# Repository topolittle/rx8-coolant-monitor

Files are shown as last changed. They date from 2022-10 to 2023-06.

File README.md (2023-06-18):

# MAZDA RX-8 Coolant monitor

The Mazda RX-8 lacks a proper gauge for displaying the coolant temperature. The stock gauge is more like a warning light than a real gauge. This project is about adding a display to the upper center console to display the coolant temperature and pressure. It also displays the battery voltage as a bonus.

This project doesn't use the OBD-II port, instead it uses dedicated sensors. The temperature sensor is from Delphi, which is very common in GM cars, and the pressure sensor is from AEM.

Although the project is for the Mazda RX-8, the electronic and the code could be used "as-is" for another car. The mechanical design, specifically the head unit, is made specific to integrate into aftermarket gauge pod, but it also should a stock RX-8 dashboard.

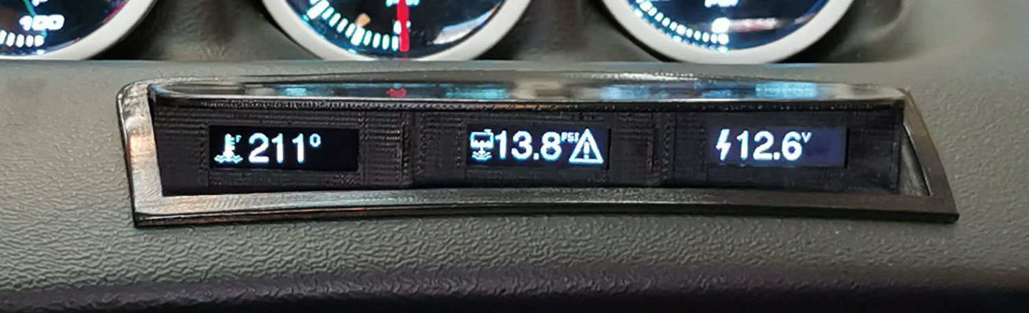
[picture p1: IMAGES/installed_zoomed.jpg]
Picture of the head unit installed in the car


# License
Except for the files listed below, this project is under the 3-clause BSD license.
## Exceptions
 - OLED_0.91_128x32.SLDASM: [This 3D drawing is from Grabcad](https://grabcad.com/library/oled-0-91-128x32-1) therefore its licenses only allows non-commercial use.
 - FreeSans18pt7bNum.h: This file contains source code from the [Adafruit-GFX-Library](https://github.com/adafruit/Adafruit-GFX-Library/) project, which is under the 2-clause BSD license. A copy of the license is provided beside the file.

# Trademarks
The RX-8 logo used in the source code provided here is a trademark of MAZDA MOTOR CORPORATION.

I am not associated with or sponsored by any of the companies mentioned in this project. I simply use their products for my personal and non-commercial use.

# Mechanical design
The mechanical design consists of two part:
- The enclosure for the PCB controller
- The head unit
## Head unit
The head unit contains three 128x32 OLED displays and it's designed to fit into a Lotek gauge pod, part #LTK-RX8-3DSH. The pod must be cut to accommodate the head unit. A cutting jig is included in the design, see below. Since the Lotek pod reproduces the same curved surface as the OEM dashboard, the design should fit a stock RX-8 without any modification.
### How to print:
Material: ASA (Do not use PLA since it will deform when exposed to the sun)
Layer height: 0.1mm
Supports: Yes, soluble for the best results
Difficulty: Expert
## Display holder
This is for holding the OLED displays in place. They require also an M3 screw each (See the BOM).
### How to print:
Material: ASA
Layer height: 0.2
Supports: No
Difficulty: Beginner
## Cutting JIG
Place the cutting JIG on the Lotek gauge pod, or on the stock dashboard pod, and mark the inside with a pen. This is where you have to cut. I used a Dremel with a small 0.5" saw blade attached to cut the pod.
### How to print:
Material: ASA, ABS or PLA
Layer height: 0.2
Supports: No
Difficulty: Beginner
## PCB Enclosure
It's a two parts enclosure: Top and bottom. The PCB goes inside and is held by four M4 screws (see the BOM). The bottom comes in two variants: One without anchor and one with two anchors for T-RAP. This can be useful if you don't want to use double sided tape to fix the enclosure inside the dashboard  

Note: Since the communication between the PCB controller and the head unit uses I2C, the controller should be placed as close to the head unit as possible. Avoid having more than 12 inches of cables between the two.
### How to print:
Material: ASA
Layer height: 0.2
Supports: No
Difficulty: Beginner
# Embedded
This is the code for the Arduino based Pro Micro. The main purpose is to read the actual values for various sensors and display the value on three independent OLED displays over I2C.
## Compile
You can use the Arduino IDE or you can use the provided devcontainer for VSCode. To do so:
1. Open the folder `EMBEDDED` with VSCode
2. View -> Command Palette
3. Type `Dev Containers: Reopen in Container`
4. Inside the container, use `ctrl_alt+R` to compile and `ctrl+alt+U` to upload  
 
Note: The devcontainer has been tested on Linux Fedora 35/36 and Oracle Linux 8.6. It might work with Windows 10+ under WSL2 but it's not tested.

## I2C multiplexing
Since the displays used here don't provide a way to configure their I2C address, the code multiplexes the data lines using extra I/O pins with the help of some *glue logic* components on the PCB.
## Temperature sensor (thermistor)
For reading the coolant temperature with a greater accuracy, an additional reference resistor is engaged at a specific temperature by a digital IO and a MOSFET on the PCB to lower the overall thermistor reference. This puts the reference resistor closer to the actual thermistor value at high temperature. A small hysteresis is in place to avoid switching back and forth the resistor too often. The conversion between the thermistor value and the actual temperature is achieved using the Steinhart-Hart equation. 
Note the project uses a Delphi temperature sensor but an AEM sensor can be used instead, see the BOM. If you want to use a different sensor than those two, you may have to adjust the three coefficients of the Steinhart-Hart equation inside the `getCoolantTempCelsius()` function.
## Reference voltage
Reading the battery voltage and the pressure sensor requires a precise reference voltage. To achieve better accuracy than using the internal Atmega 32U4 reference, an external reference voltage is used. The code reads the reference and makes appropriate corrections based on the actual read value.
## Unit of measure
You can choose between Celsius and Fahrenheit by pulling the digital I/O pin 8 high or low. The is a jumper on the PCB for that purpose.
## Customization
The file `coolant_monitor.h` contains definitions that can be customized to suit your needs. Here is the list of what you can customize:
- Coolant temperature high warning
- Coolant PSI high warning
- Battery voltage low warning
- Battery voltage high warning
- Display refresh rate
- Thermistor reference resistors
- Thermistor second reference resistor threshold and hysteresis
- Voltage divider values for the battery voltage
- Various analog to digital conversion parameters
- Various icons and logos
# Electronic
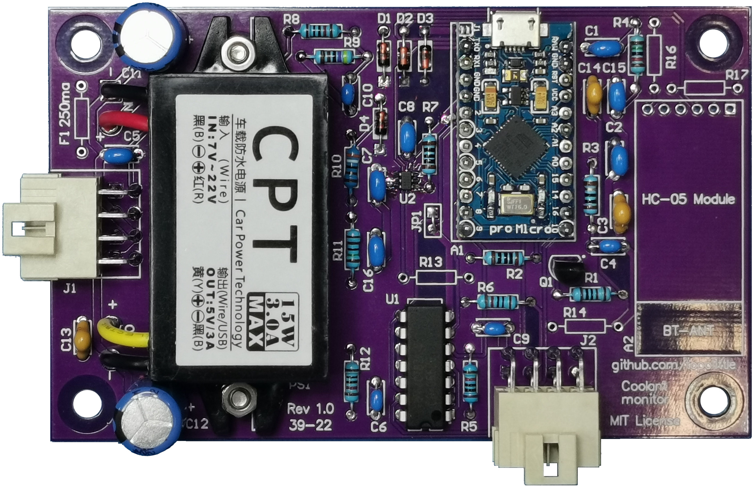
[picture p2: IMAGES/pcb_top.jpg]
Picture of the PCB, top view

A custom PCB incorporates the Adruino based Pro Micro and other important components. The main parts of this electronic design are:
- A DC-DC Converter to adapt the unstable voltage of the car (11V to 15V) to a steady 5V for the Pro Micro, sensors and other components
- A reference voltage for the various analog acquisitions performed by the Pro Micro
- The *glue logic* required to multiplex the I2C data lines
- Parking lights detection and protection circuit
- Voltage divider for reading the battery voltage
- Reference voltage for the coolant temperature thermistor
- Various signal filtration
- Connector for easily installing and removing the PCB and the enclosure from the car
- Optional Bluetooth module (not tested)
## Conformal coating
Since the PCB goes into a car, applying a silicon based conformal coating is required. Be sure to mask the connectors when doing so.
## Bluetooth
An optional Bluetooth HC-05 module can be added to control the unit. However, it doesn't have been tested as of version 1.0.  
Note: Using Bluetooth will require a custom Android app. Sorry for IOS users, it's standard Bluetooth, not Bluetooth MFI.  
Here are some future improvements which would be possible with Bluetooth:
- Over-The-Air firmware update, it may be possible with the stock bootloader, maybe not.
- Toggle the temperature units between Celsius and Fahrenheit
- Toggle the pressure units between PSI and Bar
- Display the coolant boiling point. Calculated base of a coolant/water ratio, configurable via Bluetooth
- Adjust the warning threshold for the various parameters
- Support for other sensers, configurable via Bluetooth

# Final product installed in the car
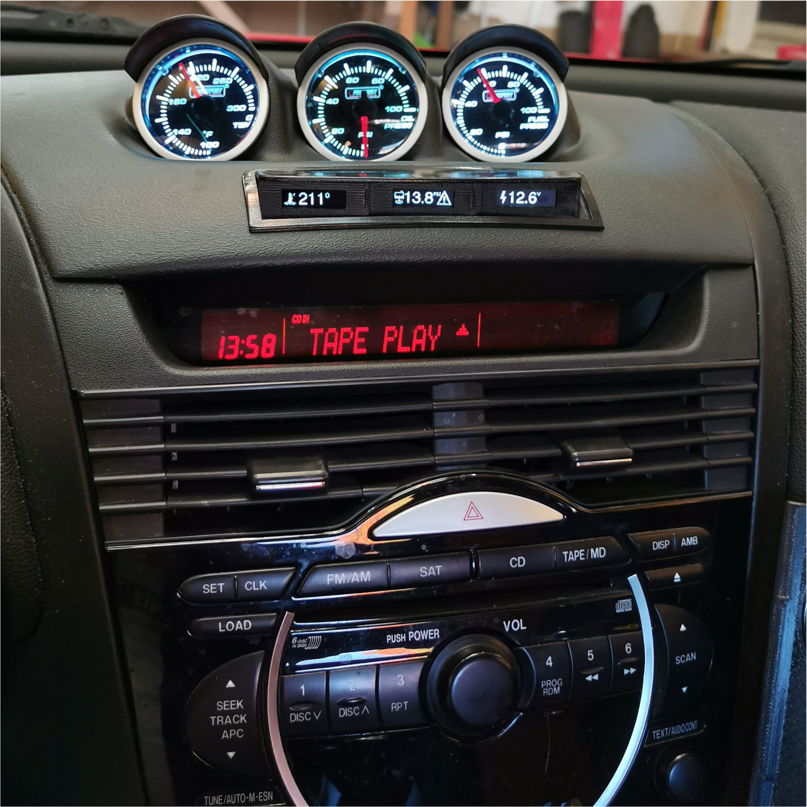
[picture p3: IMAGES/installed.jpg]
Picture of the unit installed in the car


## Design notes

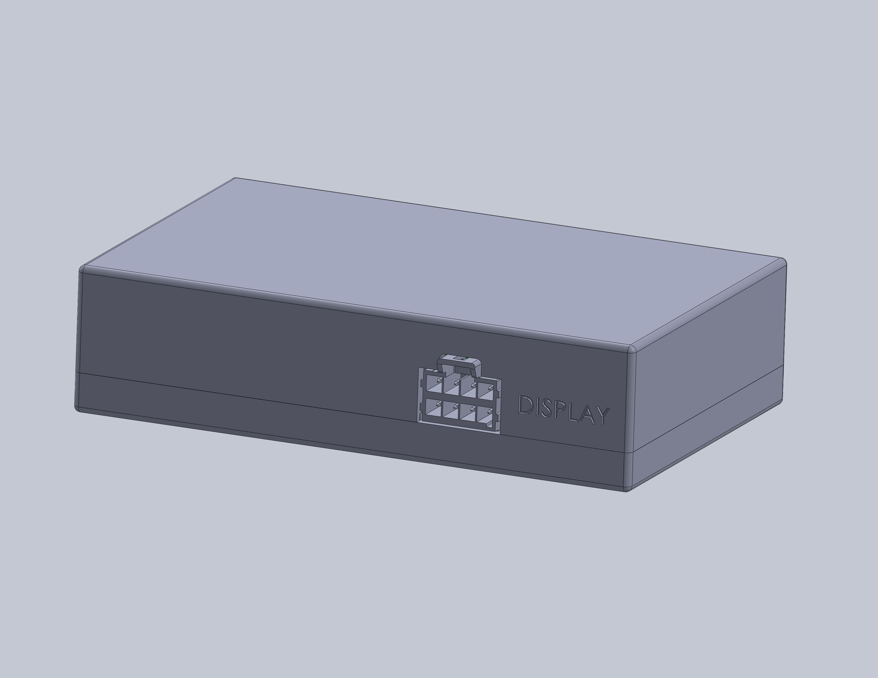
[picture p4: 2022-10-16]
MECHA/Controller_Enclosure/IMAGES/Enclosure_complete.PNG

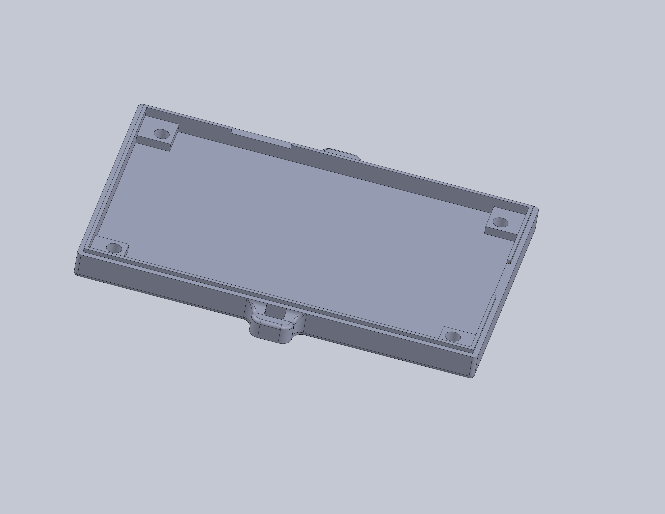
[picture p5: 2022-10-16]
MECHA/Controller_Enclosure/IMAGES/Enclosure_bottom_with_anchors.PNG

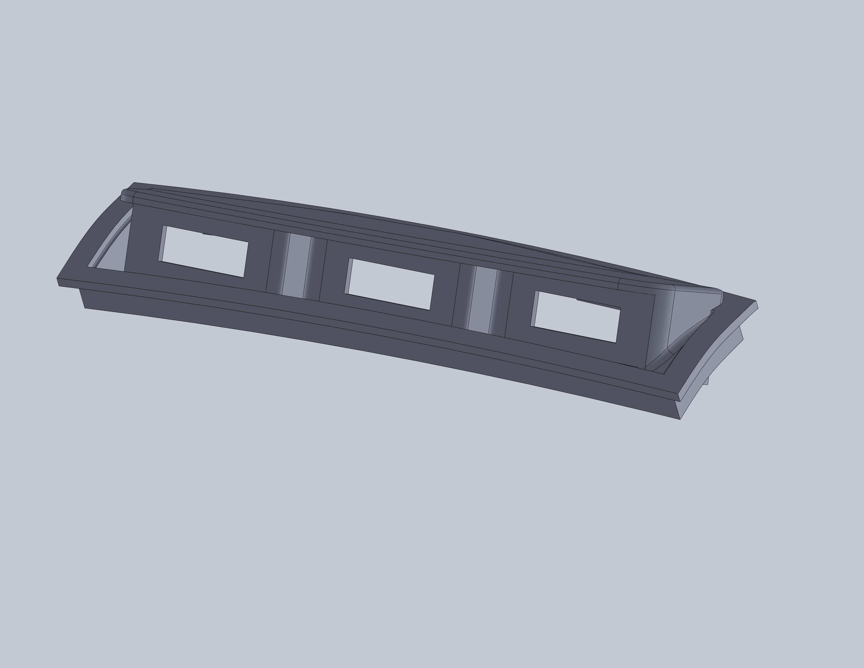
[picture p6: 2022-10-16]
MECHA/Head_Unit/IMAGES/Head_Unit.PNG

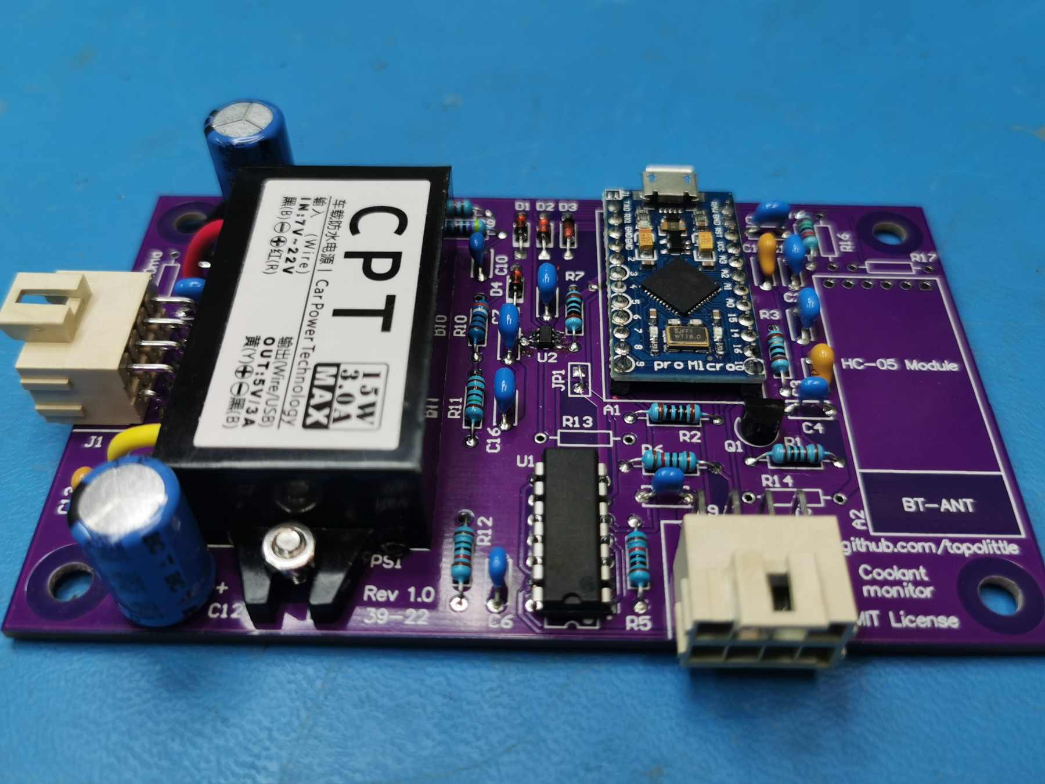
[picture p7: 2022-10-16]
IMAGES/pcb.jpg

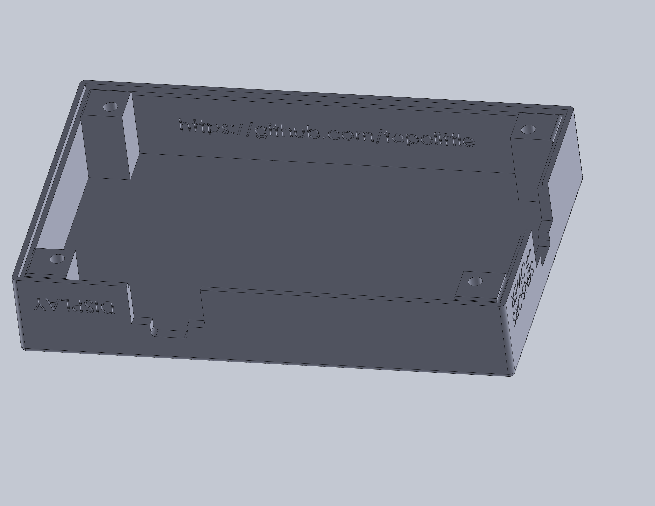
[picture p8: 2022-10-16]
MECHA/Controller_Enclosure/IMAGES/Enclosure_top.PNG

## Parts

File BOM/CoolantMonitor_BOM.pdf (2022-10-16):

Bill Of Material for RX-8 Coolant Monitor version 1.0

Main Board

Quantity Designator | Description | Value | Part # | Manufacturer | Digikey | Notes
1 A1 | Arduino MCU | Pro Micro 32U4 5V/16MHZ | DEV-12640 | Sparkfun
1 A2 | Bluetooth module | HC-05 | HC-05 | Many
7 C1, C2, C5, C7, C8, C15, C16 | Capacitor | 1uF | FG28X7R1E105KRT06 TDK | 445-173583-1-ND
3 C3, C13, C14 | Capacitor | 1nF | C315C102J3H5TA9170 Kemet | 399-17274-ND
4 C4, C6, C9, C10 | Capacitor | 0.47uF | FA24X7R1E474KNU06 TDK | 445-180634-1-ND
2 C11, C12 | Polarized Capacitor (Radial) | 470uF/25V | MAL214656471E3 | Vishay | 4473PHBK-ND
4 D1, D2, D3, D4 | High Conductance Fast Diode | 1N4148 | 1N4148 | Onsemi | 1N4148FS-ND
1 F1 | Fuse | 500MA | 0251.500NRT1L | Littlefuse | F5998CT-ND
1 J1 | 8 Pins connector | Molex 1723162108 | 1723162108 | Molex | WM11868-ND
1 J2 | 8 Pins connector | Molex 1723162108 | 1723162108 | Molex | WM11868-ND
1 JP1 | Header, 2-Pin | Jumper
1 PS1 | CPT DC-DC 12V/5V 3A | 12V->5V DC-DC | | Car Power Technology
1 Q1 | N-Channel MOSFET | 2N7000 | 2N7000 | STMicroelectronics | 497-3110-ND
1 R1 | Resistor | 1K | CF18JT1K00 | Stackpole Electronics Inc | CF18JT1K00CT-ND
2 R2, R7 | Resistor | 100 | CF18JT100R | Stackpole Electronics Inc | CF18JT100RCT-ND
1 R3 | Resistor | 10 | CF18JT10R0 | Stackpole Electronics Inc | CF18JT10R0CT-ND
1 R4 | Resistor | 14.92K | CF18JT15K0 | Stackpole Electronics Inc | CF18JT15K0CT-ND
4 R5, R6, R8, R12 | Resistor | 10K | CF18JT10K0 | Stackpole Electronics Inc | CF18JT10K0CT-ND
1 R9 | Resistor | 4.7K | CF18JT4K70 | Stackpole Electronics Inc | CF18JT4K70CT-ND
1 R10 | Resistor | 3.90K | CF18JT3K90 | Stackpole Electronics Inc | CF18JT3K90CT-ND
1 R11 | Resistor | 1.50K | CF18JT1K50 | Stackpole Electronics Inc | CF18JT1K50CT-ND
2 R13, R16 | Resistor | 1K | CF18JT1K00 | Stackpole Electronics Inc | CF18JT1K00CT-ND
2 R14, R17 | Resistor | 2K | CF18JT2K00 | Stackpole Electronics Inc | CF18JT2K00CT-ND
1 U1 | Quad bilateral switch | CD4066BE | CD4066BE | TI | 296-2061-5-ND
1 U2 | Voltage reference | MCP1502T-40E/CHY | MCP1502T-40E/CHY | Michochip | 150-MCP1502T-40E/CHYCT-ND

Wire harness

Quantity Designator | Description | Value | Part # | Manufacturer | Digikey | Notes
2 | 8 Pos. Housing receptacle | Natural white | 1722584108 | Molex | WM26327-ND
16 | Ultra-Fit tangless crimp terminal | 16-18 AWG | 1722537023 | Molex | WM26316CT-ND | For sensors and power
16 | Ultra-Fit tangless crimp terminal | 20-22 AWG | 1722537123 | Molex | WM26317CT-ND | For head unit
4 | Ultra-Fit tangless TPA | Black | 1722643004 | Molex | WM26348-ND
1 | Wire for sensors and power | 5 x 8’ + 3 x 3’ of 18 AWG
1 s | Wires for display unit | 12 x 12" of 26 AWG
3 | MTA-100 receptacle connector | 4 positions 26 AWG | 3-643815-4 | TE Connectivity (AMP) | A31026-ND | For OLED Displays

Other components

Quantity Designator | Description | Value | Part # | Manufacturer | Digikey | Notes
1 S1 | Gauge pressure sensor | 0 to 15 PSIg | 30-2131-15G | AEM
1 S2 | Temperature sensor | -40C to 150C | 12160855 | Delphi | | AEM-30-2012 can be used as a second source
3 DS1, DS2, DS3 | 0.91 Inch OLED display | 128x32 white | FC#WYTP61-WH-3 | WayinTop
1 | Main board | | | PCB Way
1 | Main board enclosure | 3d printed ASA
1 | Head unit enclosure | 3d printed ASA
1 | Aluminium hose T adapter | 34mm with 1/8 NPT threaded hole | U8301-3405 | URPG8
1 | Aluminium hose T adapter | 18mm with 1/8 NPT threaded hole | 11255 | FUPPUO
4 | Hex socket screw mushroom head | M4-0.7 x 16mm | | | | For PCB Enclosure
3 | Hex socket screw mushroom head | M3-0.5 x 6mm | | | | For display holders
2 | Hex socket screw mushroom head | M3-0.5 x 10mm | | | | For DC-DC converter
2 | Nut | M3-0.5 | | | | For DC-DC converter
1 | Silicon based conformal coating | | 422B-340G | MG Chemical | 473-1353-ND | Asalco AE130 can be used as a second source

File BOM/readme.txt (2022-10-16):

This file can be opened with LibreOffice Calc

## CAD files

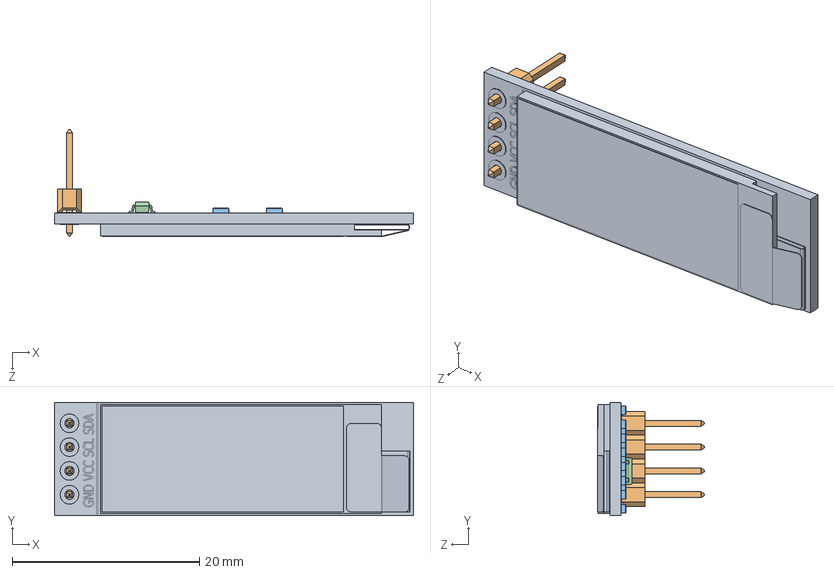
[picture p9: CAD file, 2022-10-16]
MECHA/Head_Unit/Solidworks/OLED_0.91_128x32.SLDASM
38.3 x 12.1 x 11.5 mm
OLED_0.91_128x32.stp
Pin Header 4 x 1 TH 2.54mm Pitch.stp
RESC-0603.stp x 13
2SD0601A.stp

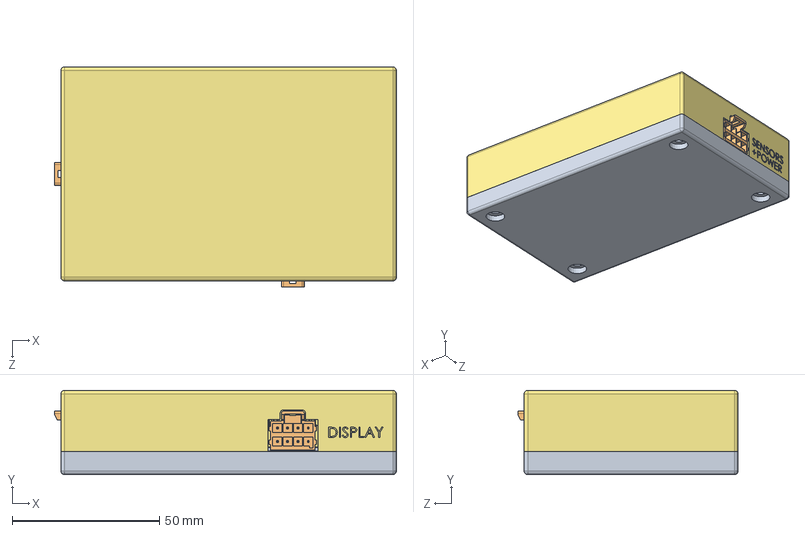
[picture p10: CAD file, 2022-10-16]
MECHA/Controller_Enclosure/Solidworks/Enclosure_with_PCB.SLDASM
116.2 x 28.6 x 74.9 mm
Enclosure_bottom
CPT_DC-DC
Extruded.step
Extruded-0.step
Board.step
Enclosure_top

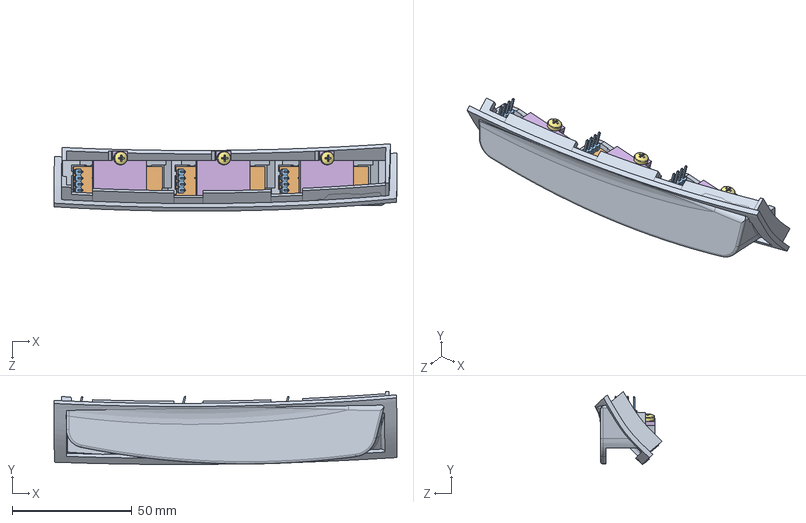
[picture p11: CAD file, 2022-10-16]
MECHA/Head_Unit/Solidworks/Head_Unit_Assembly.SLDASM
143.3 x 30.5 x 28.2 mm
Head_Unit
OLED_0.91_128x32.stp x 3
Pin Header 4 x 1 TH 2.54mm Pitch.stp x 3
RESC-0603.stp x 39
2SD0601A.stp x 3
Display_Holder_55 x 3
pan cross head_am x 3

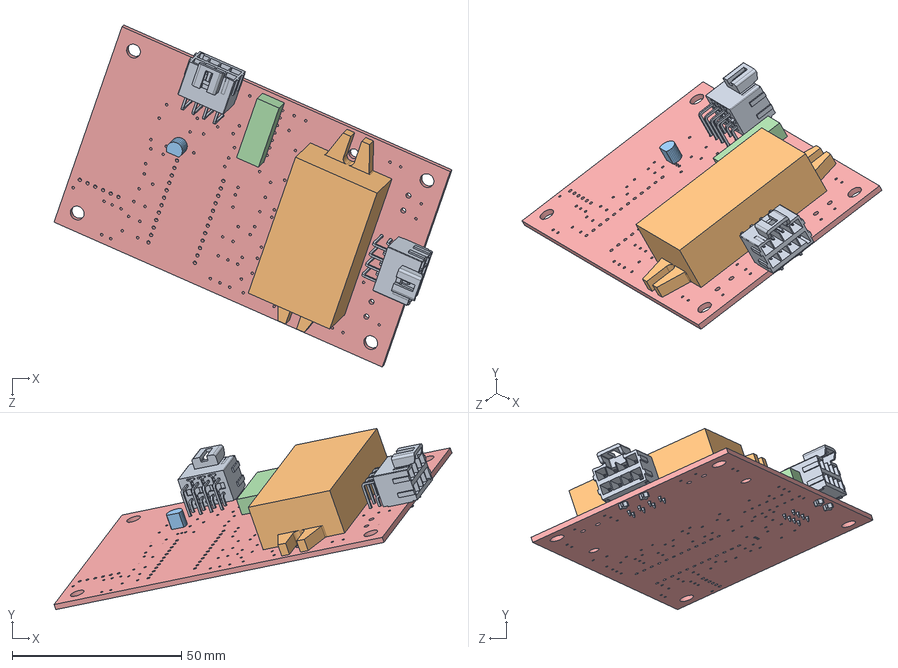
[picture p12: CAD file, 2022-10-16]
MECHA/Controller_Enclosure/Solidworks/PCB_with_parts.SLDASM
117.7 x 53.6 x 101.2 mm
CPT_DC-DC
Extruded.step
Extruded-0.step
Board.step

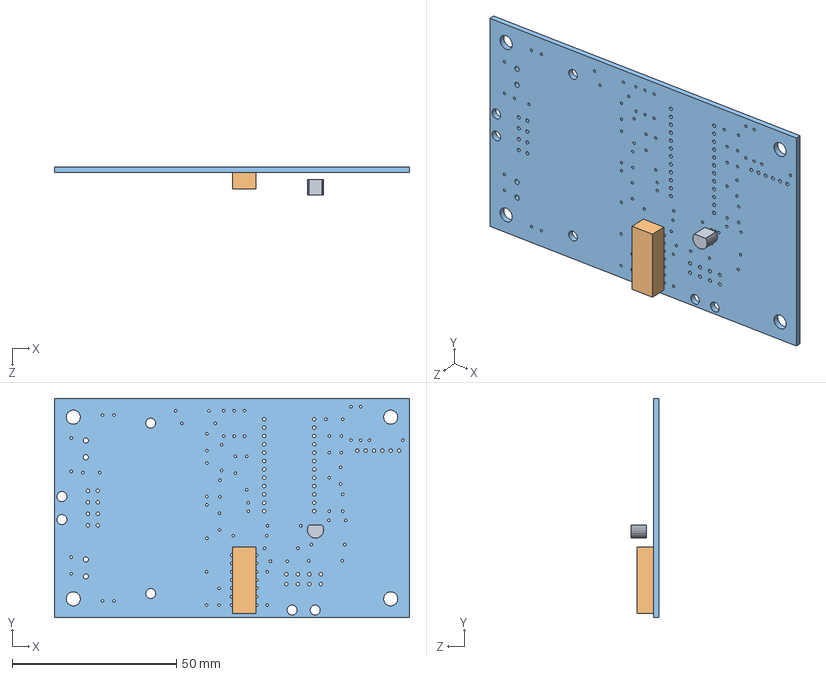
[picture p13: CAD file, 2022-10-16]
MECHA/Controller_Enclosure/Solidworks/PCB.SLDASM
107.9 x 66.7 x 8.53 mm
Extruded.step
Extruded-0.step
Board.step

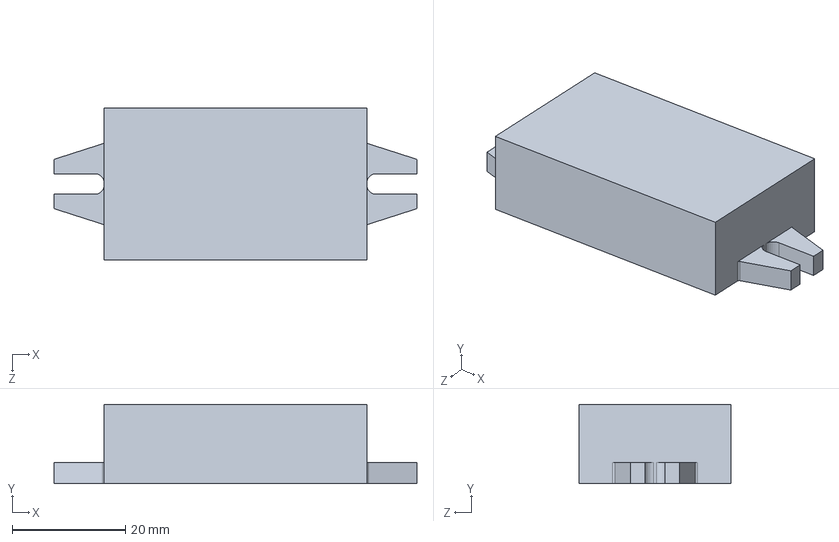
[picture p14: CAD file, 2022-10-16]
MECHA/Controller_Enclosure/Solidworks/CPT_DC-DC.SLDPRT
64.0 x 14.0 x 26.8 mm

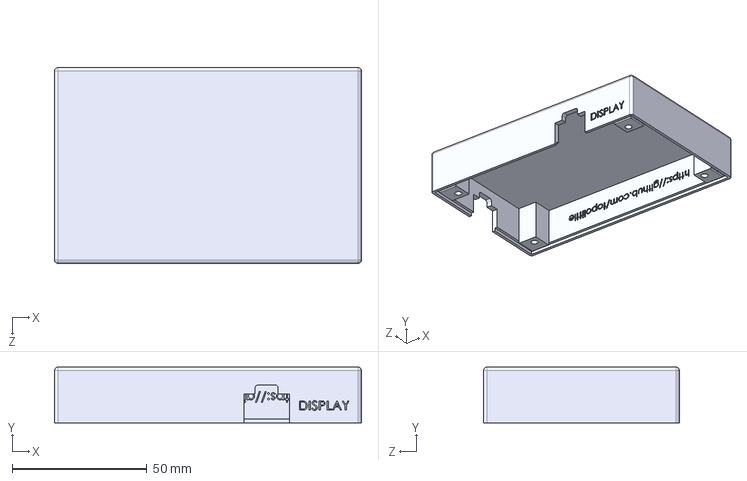
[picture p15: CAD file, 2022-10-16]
MECHA/Controller_Enclosure/STEP/Enclosure_top.STEP
114.0 x 20.7 x 72.8 mm

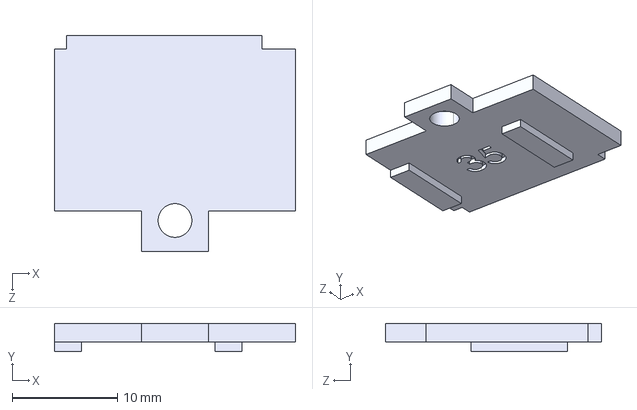
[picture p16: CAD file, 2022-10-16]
MECHA/Head_Unit/STEP/Display_Holder_35.STEP
22.9 x 2.67 x 20.4 mm

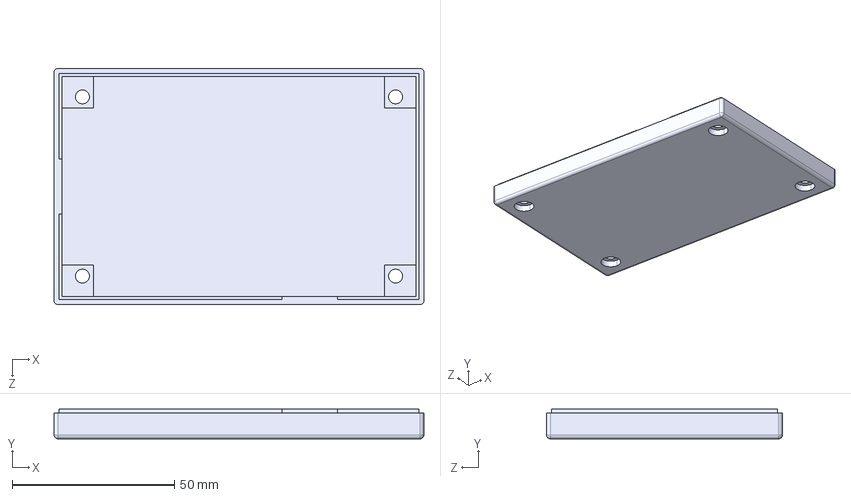
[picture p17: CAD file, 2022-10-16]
MECHA/Controller_Enclosure/STEP/Enclosure_bottom.STEP
114.0 x 9.19 x 72.8 mm

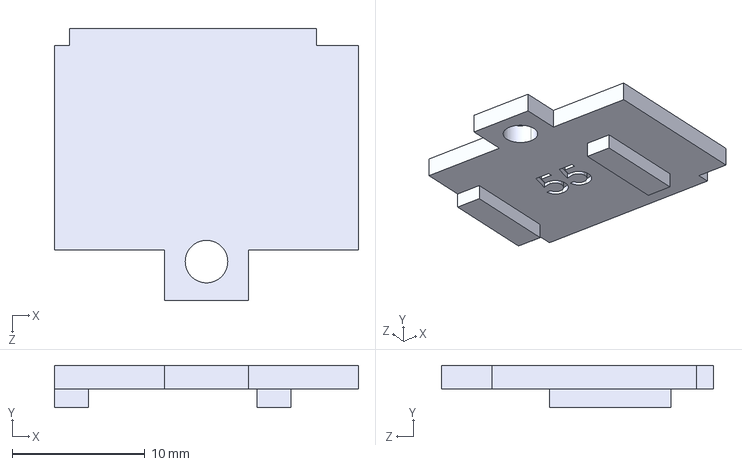
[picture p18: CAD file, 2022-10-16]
MECHA/Head_Unit/STEP/Display_Holder_55.STEP
22.9 x 3.18 x 20.4 mm

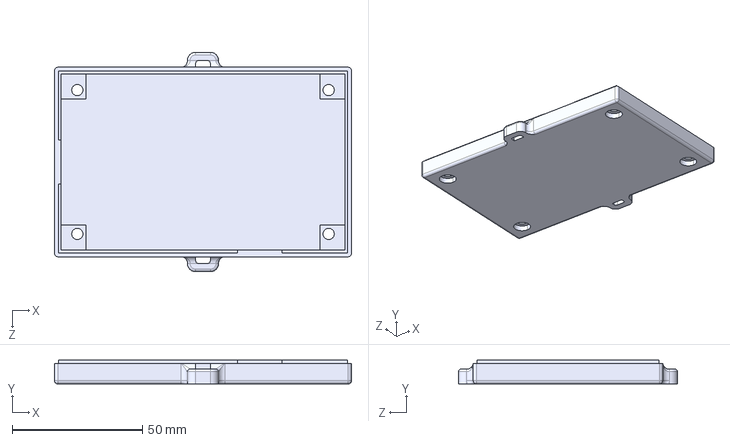
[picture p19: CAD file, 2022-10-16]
MECHA/Controller_Enclosure/STEP/Enclosure_bottom_with_anchors.STEP
114.0 x 9.20 x 84.2 mm

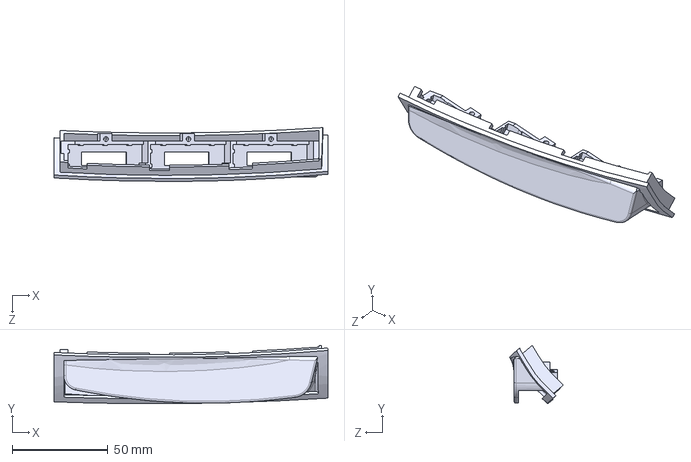
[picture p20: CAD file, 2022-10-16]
MECHA/Head_Unit/STEP/Head_Unit.STEP
143.3 x 30.5 x 28.1 mm

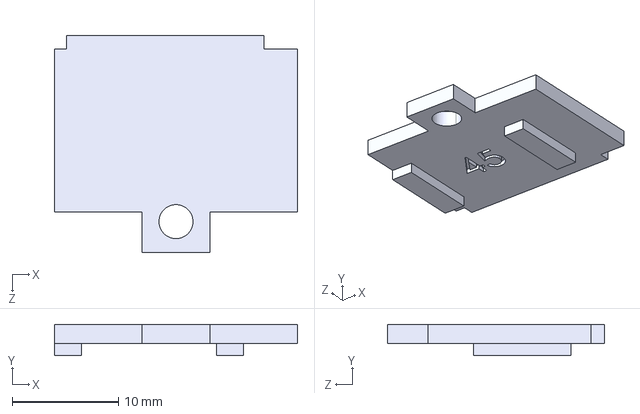
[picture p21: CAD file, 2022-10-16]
MECHA/Head_Unit/STEP/Display_Holder_45.STEP
22.9 x 2.92 x 20.4 mm

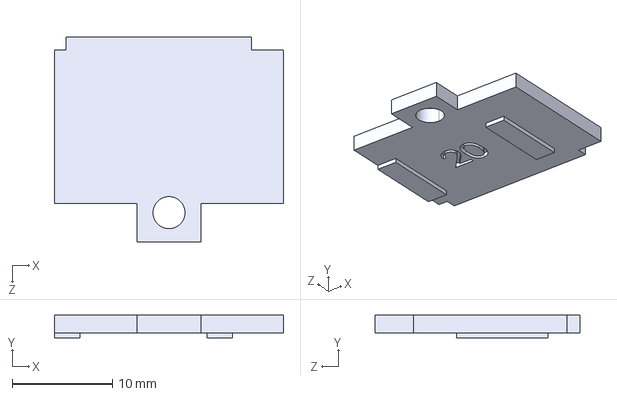
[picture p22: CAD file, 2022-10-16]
MECHA/Head_Unit/STEP/Display_Holder_20.STEP
22.9 x 2.29 x 20.4 mm

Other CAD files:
MECHA/Head_Unit/STEP/Head_Unit_cutting_jig.STEP
MECHA/Controller_Enclosure/Solidworks/1723162108.SLDPRT
MECHA/Controller_Enclosure/STL/Enclosure_bottom.STL
MECHA/Controller_Enclosure/STL/Enclosure_bottom_with_anchors.STL
MECHA/Controller_Enclosure/STL/Enclosure_top.STL
MECHA/Controller_Enclosure/Solidworks/Enclosure_bottom.SLDPRT
MECHA/Controller_Enclosure/Solidworks/Enclosure_bottom_with_anchors.SLDPRT
MECHA/Controller_Enclosure/Solidworks/Enclosure_top.SLDPRT
MECHA/Head_Unit/STL/Display_Holder_20.STL
MECHA/Head_Unit/STL/Display_Holder_35.STL
MECHA/Head_Unit/STL/Display_Holder_45.STL
MECHA/Head_Unit/STL/Display_Holder_55.STL
MECHA/Head_Unit/STL/Head_Unit.STL
MECHA/Head_Unit/STL/Head_Unit_cutting_jig.STL
MECHA/Head_Unit/Solidworks/Display_Holder_20.SLDPRT
MECHA/Head_Unit/Solidworks/Display_Holder_35.SLDPRT
MECHA/Head_Unit/Solidworks/Display_Holder_45.SLDPRT
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

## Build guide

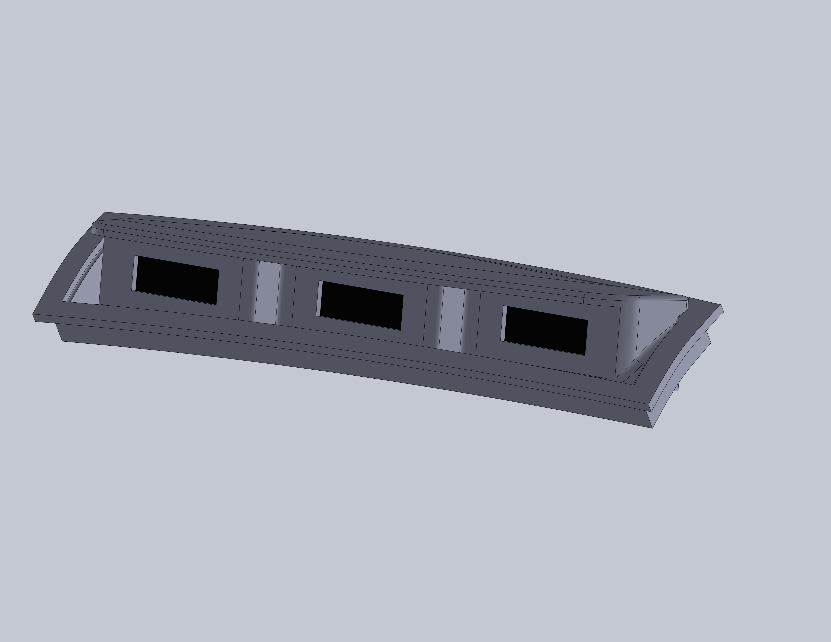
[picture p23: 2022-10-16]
MECHA/Head_Unit/IMAGES/Head_Unit_Assembly_front.PNG

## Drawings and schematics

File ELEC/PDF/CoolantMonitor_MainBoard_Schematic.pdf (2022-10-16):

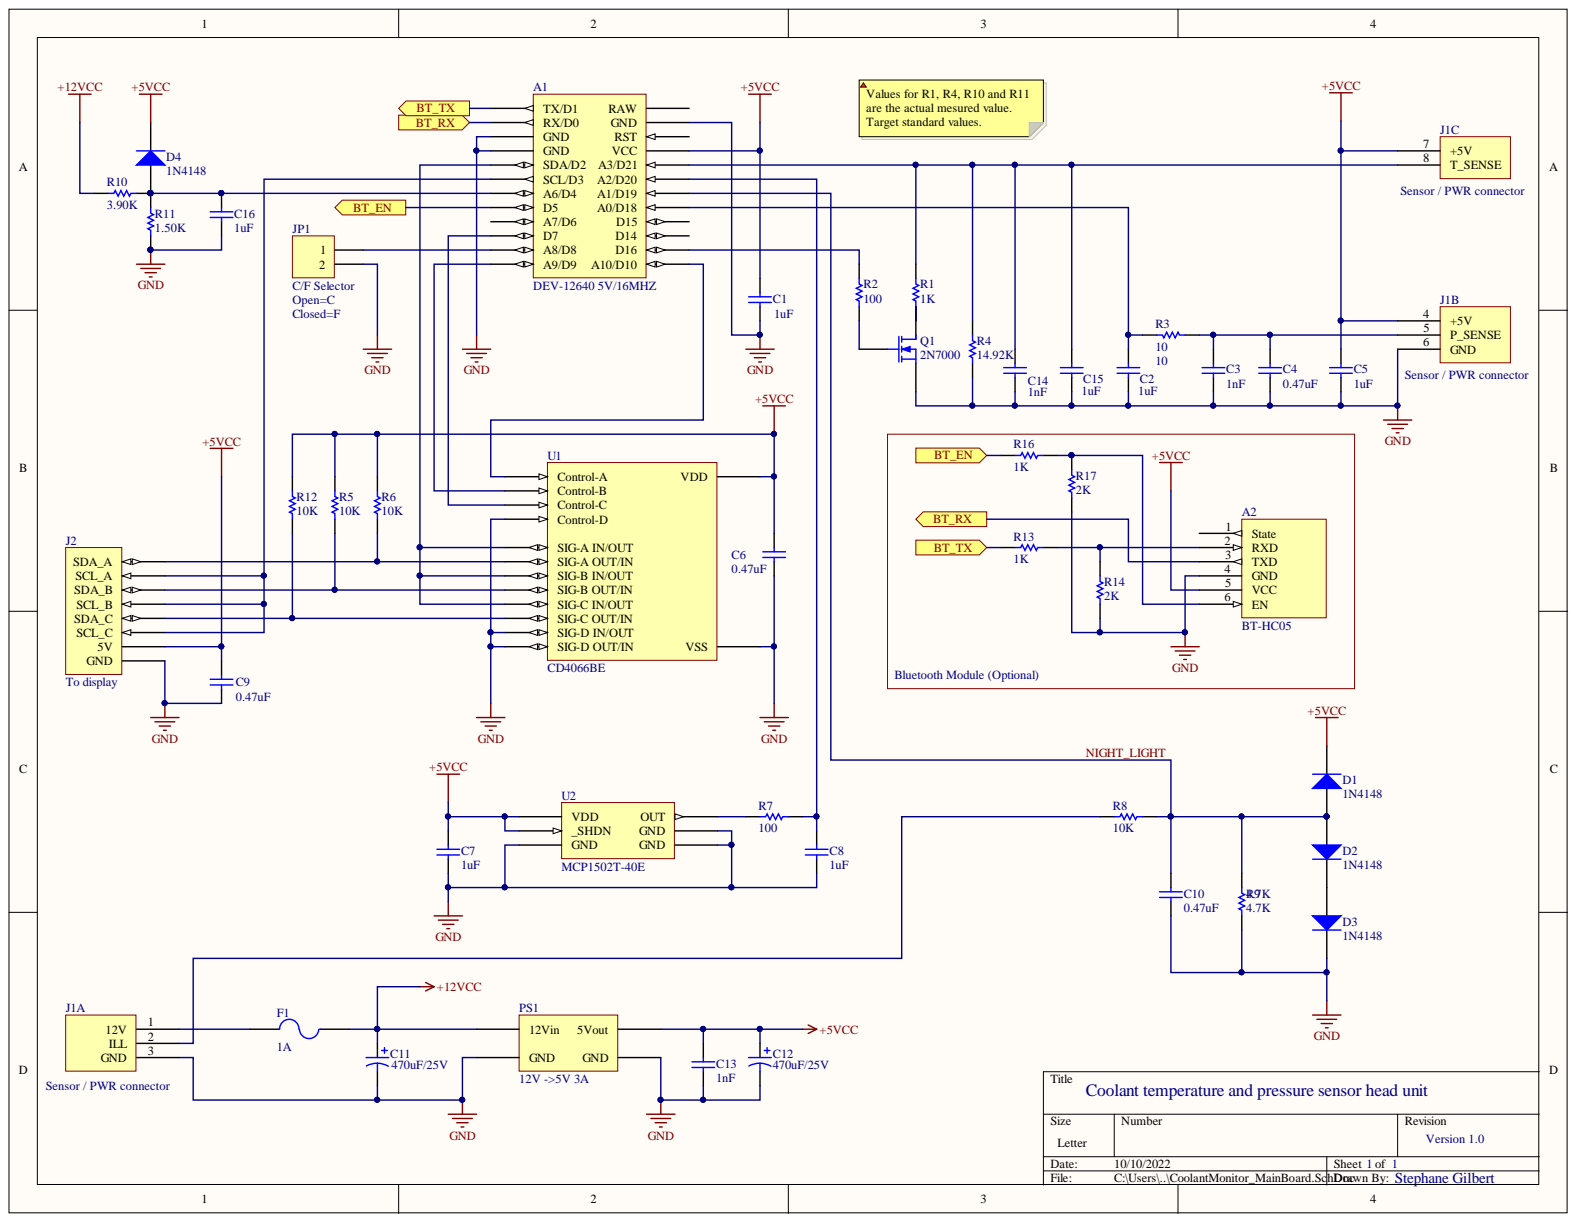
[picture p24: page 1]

Values for R1, R4, R10 and R11
are the actual mesured value.
Target standard values.

+5VCC

GND 4

Title
Coolant temperature and pressure sensor head unit

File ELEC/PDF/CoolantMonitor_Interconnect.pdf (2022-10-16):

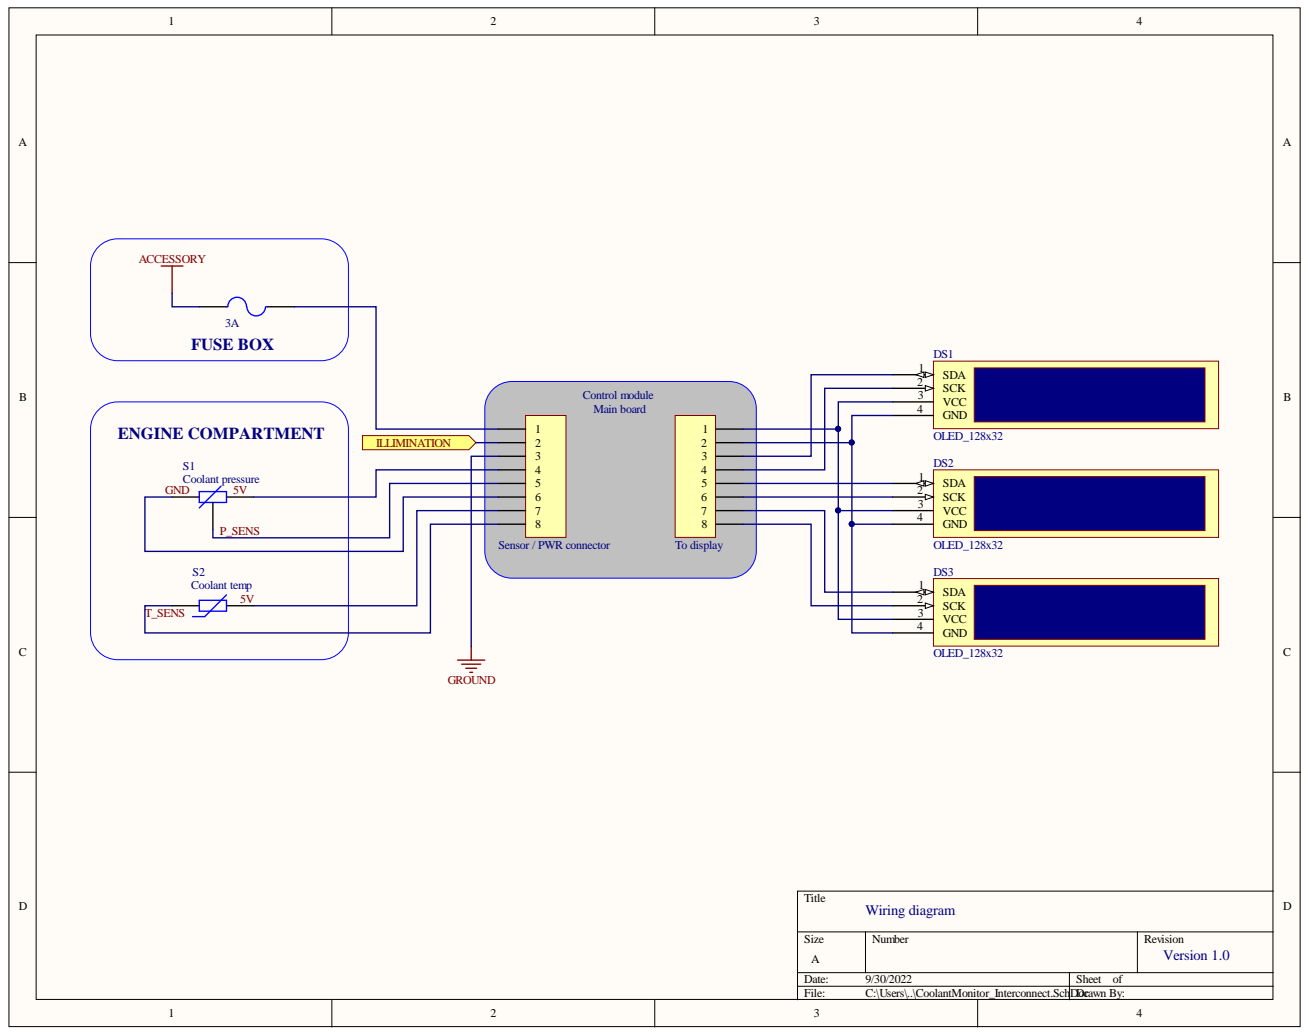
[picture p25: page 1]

SCK 2 SDA 1

VCC 3

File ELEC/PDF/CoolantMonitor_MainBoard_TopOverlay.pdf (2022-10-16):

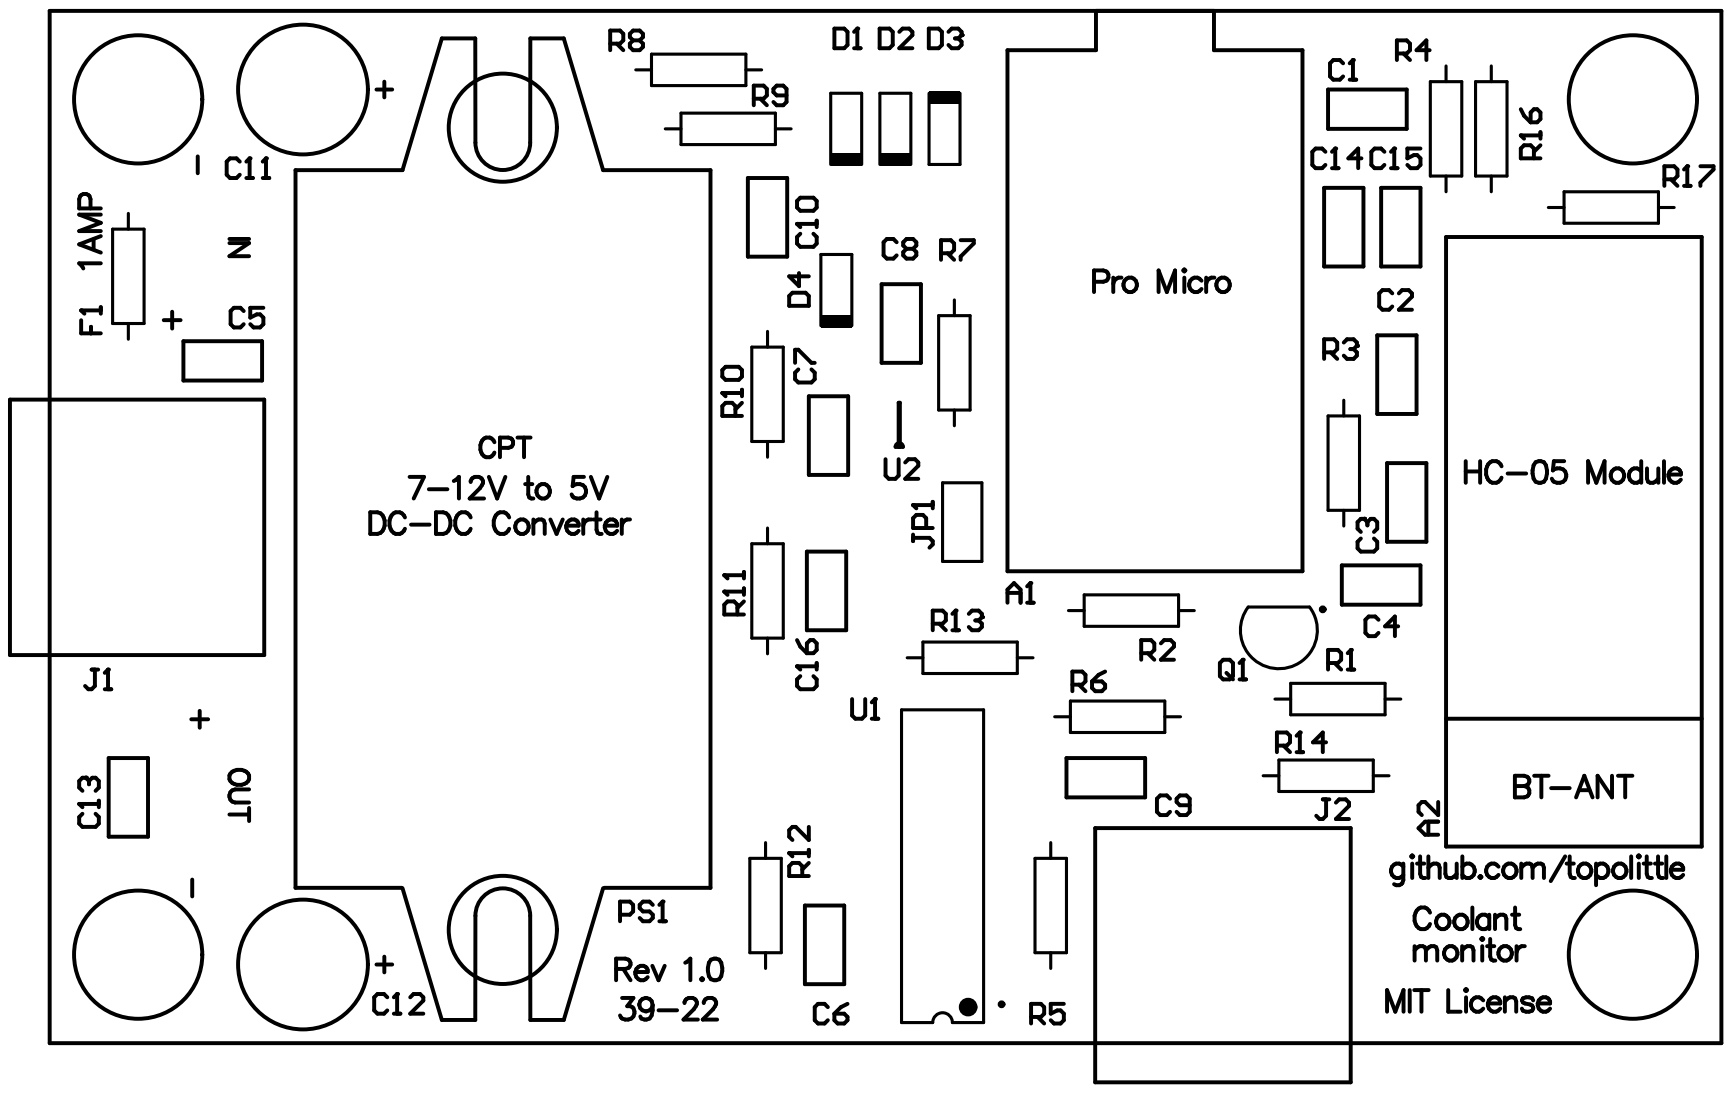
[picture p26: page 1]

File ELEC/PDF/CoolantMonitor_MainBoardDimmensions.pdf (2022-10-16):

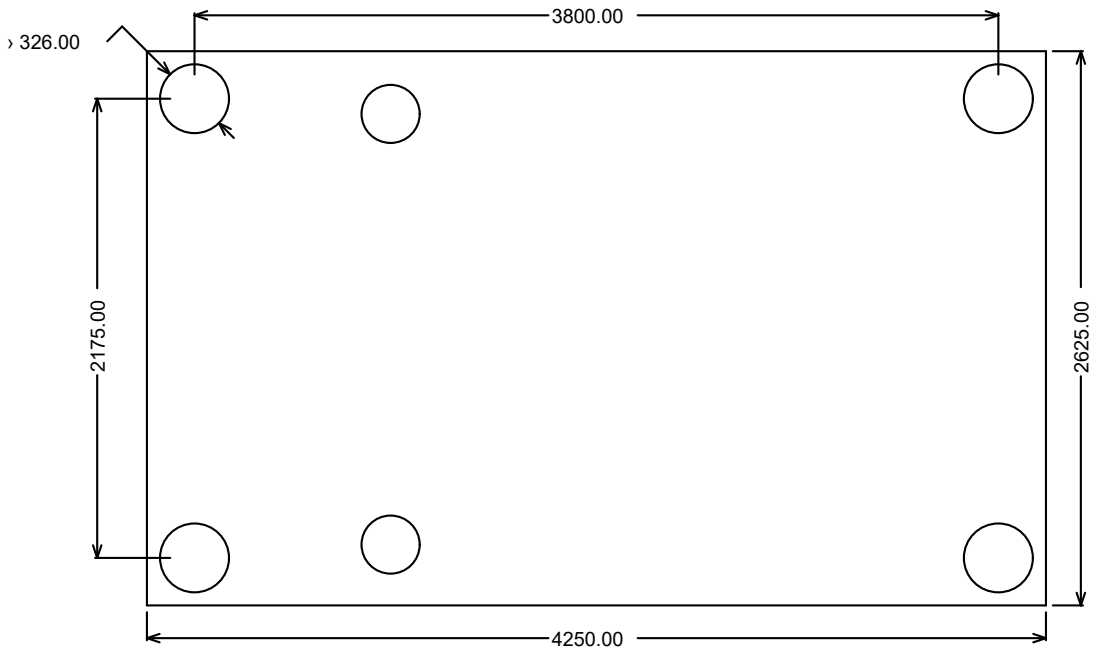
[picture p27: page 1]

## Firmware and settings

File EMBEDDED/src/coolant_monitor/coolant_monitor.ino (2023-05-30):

/* 
 * This is the main source code for the RX-8 coolant monitor project.
 * It targets an Arduino based Pro Micro.
 * Author: Stephane Gilbert
 * BSD tree clause licence (SPDX: BSD-3-Clause)
*/

#include <Wire.h>
#include <Adafruit_GFX.h>
#include <Adafruit_SSD1306.h>
#include "coolant_monitor.h"
#include "FreeSans18pt7bNum.h"

#define OLED_RESET 4 // Reset for Adafruit SSD1306

// Using this constructor to have the maximum I2C communication speed.
Adafruit_SSD1306 display_1(128, 32, &Wire, OLED_RESET);
Adafruit_SSD1306 display_2(128, 32, &Wire, OLED_RESET);
Adafruit_SSD1306 display_3(128, 32, &Wire, OLED_RESET);

Adafruit_SSD1306* displays [] = { &display_1, &display_2, &display_3 };
uint8_t display_count = sizeof(displays) / sizeof(Adafruit_SSD1306*);

// Values to cache the current reading in memory
float current_coolant_temp;
float current_coolant_psi;
float current_supply_voltage;
bool thermistor_reference_mode_high = true;
bool temperatureUnitIsFahrenheit = false;
bool currentDaylight = true;

// Select the specified display. All further write operation will go to that display
// display: An instance reference of the Adafruit_SSD1306 class
void selectDisplay(Adafruit_SSD1306 &display)
{
    if ((int)&display == (int)&display_1) {
        digitalWrite(DISPLAY_2_SELECT_OUTPUT_PIN, LOW);
        digitalWrite(DISPLAY_3_SELECT_OUTPUT_PIN, LOW);
        digitalWrite(DISPLAY_1_SELECT_OUTPUT_PIN, HIGH);
    }

    if ((int)&display == (int)&display_2) {
        digitalWrite(DISPLAY_1_SELECT_OUTPUT_PIN, LOW);
        digitalWrite(DISPLAY_3_SELECT_OUTPUT_PIN, LOW);
        digitalWrite(DISPLAY_2_SELECT_OUTPUT_PIN, HIGH);
    }

    if ((int)&display == (int)&display_3) {
        digitalWrite(DISPLAY_1_SELECT_OUTPUT_PIN, LOW);
        digitalWrite(DISPLAY_2_SELECT_OUTPUT_PIN, LOW);
        digitalWrite(DISPLAY_3_SELECT_OUTPUT_PIN, HIGH);
    }
}

// Read the specified analog input pin many times and return the mean
// pin: The pin on which the analog read will occur
// Return: A float between 0 and 1023 representing the analog value on the specieid pin
float readAnalogInputRaw(uint8_t pin)
{
    uint16_t cumulative_value = 0;
    int single_value;

    // The first read is a dummy read only to warm up the ADC, so we Loop from zero to
    // ANALOG_SAMPLES_COUNT inclusively, in fact ANALOG_SAMPLES_COUNT + 1 times.
    for (size_t i = 0; i <= ANALOG_SAMPLES_COUNT; i++)
    {
        single_value = analogRead(pin);

        // If it's the first read, force the value to zero, it it will not be taken into account
        cumulative_value += i > 0 ? single_value : 0;
        delay(ANALOG_DELAY_BETWEEN_ACQUISITIONS);
    }

    // Return the arithmetic mean
    return (float)cumulative_value / (float)ANALOG_SAMPLES_COUNT;
}

// Returns the voltage on the specified pin using an external reference voltage for maximum accuracy
// pin: The pin on which the analog read will occur
// Return: A float representing the voltage read at the specified pin
float readVoltage(uint8_t pin)
{
    float reference = readAnalogInputRaw(REFERENCE_ANALOG_INPUT_PIN);
    float value = readAnalogInputRaw(pin);

    return (ANALOG_REFERENCE_VOLTAGE * value) / reference;
}

// Invalidate the display value so the next reading will force the display to be redrawn
// display: An instance reference of the Adafruit_SSD1306 class
void forceDisplayRefresh(Adafruit_SSD1306 &display)
{
    if ((int)&display == (int)&display_1)
        current_coolant_temp = __FLT_MIN__;

    if ((int)&display == (int)&display_2)
        current_coolant_psi = __FLT_MIN__;

    if ((int)&display == (int)&display_3)
        current_supply_voltage = __FLT_MIN__;
}

// Draw an icon using specified display object
// display: An instance reference of the Adafruit_SSD1306 class
// icon: The specific icon to draw, emum value
// xpos, ypos: The top left corner to start the drawing 
void drawIcon(Adafruit_SSD1306 &display, const Icon icon, const uint8_t xpos, const uint8_t ypos)
{
    display.drawBitmap(
        (uint16_t)xpos,
        (uint16_t)ypos,
        epd_bitmap_allArray[(uint8_t)icon],
        pgm_read_byte(&iconSize[(uint8_t)icon].width),
        pgm_read_byte(&iconSize[(uint8_t)icon].height),
        1);
}

// Draw the warning icon using the the specified display object
// display: An instance reference of the Adafruit_SSD1306 class, the display to write to
void drawWarning(Adafruit_SSD1306 &display)
{
    drawIcon(display, Icon::warning_icon, 95, 0);
}

// Display a fault message using the the specified display object
// display: An instance reference of the Adafruit_SSD1306 class, the display to write to
// Note: The display is cleared, draw and updated
void displayFault(Adafruit_SSD1306 &display)
{
    display.clearDisplay();
    drawIcon(display, Icon::fault_message, 11, 3);
    selectDisplay(display);
    display.display();

    // Ensure if we go out of fault, the display will refresh the actual value
    forceDisplayRefresh(display);
}

// Sets the reference resistor (pull down) for the thermistor
// value: True to set the high resistor value, False to select the low resistor value.
void setThermistorHighReference(const bool value)
{
    // The logic is inverted here by the 2n7000 on the PCB
    digitalWrite(THERMISTOR_REFERENCE_SELECT_OUTPUT_PIN, value ? LOW : HIGH);
    thermistor_reference_mode_high = value;
}

// Convert the provided temperature from Celsius to Fahrenheit
// temperature: The temperature to convert from Celsius
// Return: A float representing the converted temperature, in Fahrenheit
float convertToFahrenheit(float temperature)
{
    return temperature * 9.0 / 5.0 + 32.0;
}

// Read the thermistor resistor value and convert it to temperature in Celsius
// using the Steinhart-Hart equation.
// TC: The variable that will hold the returned temperature value
// Return: ENOERR if the conversion succeeded and the value has been placed in the TC parameter, otherwise the error code
// Note: The function also manage the pull-down resistor set related to the sensor
int getCoolantTempCelsius(float &TC)
{
    float tResValue;
    float logTResValue;
    float TK;
    float analogValue;

    // The constant values for the AEM-30-2012 have been calculated with this online calculator:
    // https://www.thinksrs.com/downloads/programs/therm%20calc/ntccalibrator/ntccalculator.html
    // The reference resistor and temperature used for the calculator was extracted from the
    // following datasheet from AEM:
    // https://www.aemelectronics.com/files/instructions/30-2012%20Sensor%20Data.pdf
    float c1 = 1.144169514e-3;   // -40C, 402392 OHMs
    float c2 = 2.302830665e-4;   // 50C, 3911 OHMs
    float c3 = 0.8052469400e-7;  // 150C, 189.3 OHMs

    // Get the analog value on the input pin
    analogValue = readAnalogInputRaw(COOLANT_ANALOG_INPUT_PIN);

    // Avoid dividing by zero
    if (analogValue == 0) {
        return EDIVZERO;
    }

    // Discard any values that do not make sense
    if (analogValue < 0) {
        return ERANGE;
    }

    // Use the correct pull down resistor reference value according to the actual configured value
    float t_res_ref = thermistor_reference_mode_high ? THERMISTOR_RESISTOR_REFERENCE_HIGH : THERMISTOR_RESISTOR_REFERENCE_LOW;

    // Compute the thermistor resistor value, using the equation R2 = R1 * (Vin / Vout - 1)
    tResValue = t_res_ref * (1023.0 / ((float)analogValue) - 1.0);

    // Convert the thermistor resistor value to temperature in Kelvin using the Steinhart-Hart equation
    logTResValue = log(tResValue);
    TK = (1.0 / (c1 + c2 * logTResValue + c3 * logTResValue * logTResValue * logTResValue));

    // Ensure the temperature is between the sensor range: 233.15K to 425.15K (-40C to 150C)
    if (TK < 233.15 || TK > 423.15) {
        return ERANGE;
    }

    // Convert the temperation from Kelvin to Celsius
    TC = TK - 273.15;

    // Manage the pull-down resistor reference for the next run
    if (thermistor_reference_mode_high && TC > THERMISTOR_RESISTOR_REFERENCE_LOW_TRESHOLD)
        setThermistorHighReference(false);

    if (! thermistor_reference_mode_high && TC < THERMISTOR_RESISTOR_REFERENCE_HIGH_TRESHOLD)
        setThermistorHighReference(true);

    return ENOERR;
}

// Get the Coolant pressure in PSI.
// psi: The variable that will hold the returned PSI value
// Return: ENOERR if the conversion succeeded and the value has been placed in the psi
//         parameter, otherwise the error code
int getCoolantPsi(float &psi)
{
    float volts;
    volts = readVoltage(PSI_ANALOG_INPUT_PIN);

    // Ensure the voltage is between the sensor range, otherwise return an error
    if (volts < 0.2 || volts > 4.8) {
        return ERANGE;
    }

    // Convert voltage to PSI
    // According to this datasheet, PSI = (3.7529*(Voltage)) - 1.8765
    // https://www.aemelectronics.com/files/instructions/30-2131-15G%20Sensor%20Data.pdf
    psi = 3.7529 * volts - 1.8765;
    if (psi < 0)
        psi = 0;

    return ENOERR;
}

// Read the supply voltage before the DC-DC converter
// It should be between 11.5 and 14.5
// voltage: The variable that will hold the returned voltage value
// Return: ENOERR if the conversion succeeded and the value has been placed in the voltage
//         parameter, otherwise the error code
int getSupplyVoltage(float &voltage)
{
    float volts, supply_voltage;
    volts = readVoltage(VOLTAGE_ANALOG_INPUT_PIN);

    // Convert pin voltage to actual voltage based on the onboard tension divider
    supply_voltage = volts / (VOLTAGE_DIVIDER_R2 / (VOLTAGE_DIVIDER_R1 + VOLTAGE_DIVIDER_R2));

    // We can't be alive and have a supply voltage below 7V at the same time
    if (supply_voltage < 7)
        return ERANGE;

    voltage = supply_voltage;
    return ENOERR;
}

// Return true if the illumination (pakring lights) are turned off, otherwise false
// Valid voltage are between 0V and 15V. Anything below 1.7v is considered day lignt
// Note: There a voltage divisor on the board that divide by roughly 3.127
// 10K and 4.7K = 14.7K / 4.7K = 3.127
// So 1.7V input would read .543V and 16V would read 4.79V at the analog pin
// Note: There is no needs to use high precision function here. A simple analog read
// is good enaugh.
bool isDayLight()
{
    float v;
    v = (float)analogRead(ILLUMINATION_ANALOG_INPUT_PIN) * (5.0 / 1023.0);
    return (v < 0.5) ? true : false;
}

// If daylight is true, set all display to their maximum luminosity, dim them otherwise
void setDayLight(bool dayLight)
{
    currentDaylight = dayLight;
    for (size_t d = 0; d < display_count; d++)
    {
        selectDisplay(*displays[d]);
        displays[d]->dim(!dayLight);
    }
}

// Ensure the display intensity is set according to the current daylight status
void processDayLight()
{
    bool dayLight = isDayLight();
    if (dayLight != currentDaylight) {
        setDayLight(dayLight);
    }
}

// Update the temperature on the specified display with the specified temperature.
// If the Fahrenheit selector jumper has been present during boot time, display the
// temperature in Fahrenheit, display in Celsius otherwise.
// display: An instance of the Adafruit_SSD1306 class representing the display
//          on wich the value will be displayed
// temperature: The temperature to display, in Celsius
void updateCoolant(Adafruit_SSD1306 &display, float temperature)
{
    current_coolant_temp = temperature;
    selectDisplay(display);
    display.clearDisplay();

    // Print the coolant value and the icon according to the desired units
    display.setCursor(TEXT_POS_X, TEXT_POS_Y + 24);
    if (! temperatureUnitIsFahrenheit) {
        // Jumper not present, Display in Celsius
        drawIcon(display, Icon::coolant_icon_c, 0, 5);
        display.print(round(temperature));
    } else {
        // Jumper present. Convert to Fahrenheit
        drawIcon(display, Icon::coolant_icon_f, 0, 5);
        display.print(round(convertToFahrenheit(temperature)));
    }

    // Print the degree sign after the numeric value
    drawIcon(display, Icon::degree_sign, display.getCursorX() + 1, TEXT_POS_Y);

    // Print a warning if we have to
    if (temperature >= COOLANT_TEMP_WARNING_CELSIUS)
        drawWarning(display);

    display.display();
}

// Update the PSI on the specified display with the provided value
// display: An instance of the Adafruit_SSD1306 class representing the display
//          on wich the value will be displayed
// psi: The pressure in PSI
void updatePsi(Adafruit_SSD1306 &display, float psi)
{
    current_coolant_psi = psi;

    selectDisplay(display);
    display.clearDisplay();
    drawIcon(display, Icon::radiator_pressure_icon, 0, 3);

    // Print the PSI value
    // Move slightly the displayed value to the left if we are in warning state to give room for the warning sign
    display.setCursor(TEXT_POS_X - (psi < COOLANT_PSI_WARNING ? 0 : 10), TEXT_POS_Y + 24);
    display.print(psi, 1);

    // Print the PSI sign
    drawIcon(display, Icon::psi_sign, display.getCursorX() + 1, TEXT_POS_Y);
    
    if (psi >= COOLANT_PSI_WARNING)
        drawWarning(display);

    display.display();
}

// Update the supply voltage on the specified display with the provided value
// display: An instance of the Adafruit_SSD1306 class representing the display
//          on wich the value will be displayed
// voltage: The voltage value to display
void updateSupplyVoltage(Adafruit_SSD1306 &display, float voltage)
{
    current_supply_voltage = voltage;

    selectDisplay(display);
    display.clearDisplay();
    drawIcon(display, Icon::voltage_icon, 6, 3);

    display.setCursor(TEXT_POS_X - (voltage < 10.0 ? 0 : 8), TEXT_POS_Y + 24);
    display.print(voltage, 1);
     
     // Print the voltage sign
    drawIcon(display, Icon::voltage_sign, display.getCursorX() + 1, TEXT_POS_Y);

    if (voltage < BATTERY_VOLTAGE_LOW_WARNING || voltage > BATTERY_VOLTAGE_HIGH_WARNING)
        drawWarning(display);

    display.display();
}

// Display a small animation
// The logo width must be a multiple of 8. Typically, 8 bits in an unsigned char
void displayIntro()
{
    // The icon to use for the animation
    const Icon icon = Icon::rx8_logo;

    // Compute the size of an unsigned char in bits
    const uint8_t u_char_bits_size = sizeof(unsigned char) * __CHAR_BIT__;

    // Get a pointer to the logo bitmap array. We will need it to display only some parts of the image
    const unsigned char* logo_ptr { epd_bitmap_allArray[(uint8_t)icon] };

    // Get the logo size in pixels
    uint8_t width = pgm_read_byte(&iconSize[(uint8_t)icon].width);
    uint8_t height = pgm_read_byte(&iconSize[(uint8_t)icon].height);

    for (size_t x = u_char_bits_size - 1; x < width; x = x + u_char_bits_size)
    {
        for (size_t d = 0; d < display_count; d++)
        {
            displays[d]->clearDisplay();
        }

        for (size_t y = 0; y < height; y++)
        {
            for (size_t d = 0; d < display_count; d++)
            {
                displays[d]->drawBitmap(0, y + (display_1.height() - height) / 2, logo_ptr + y * width / u_char_bits_size  + (width - x - 1) / u_char_bits_size, x + 1, 1 ,1);
            }
        }

        for (size_t d = 0; d < display_count; d++)
        {
            selectDisplay(*displays[d]);
            displays[d]->display();
        }

        // Adjust the delay to have a smooth animation.
        // As more parts of the image is drawn, the more time it take to transfert it with i2c.
        delay((width - x) / 3);
        processDayLight();
    }

    delay(3000);
}

// Configures the Arduino IO pins
// All unused pins are put in three state with pull-ups
void configureIOs()
{
    // Set VCC as analog reference
    analogReference(DEFAULT);

    // Unused pins
    //pinMode(UNUSED_PIN_0, INPUT_PULLUP);
    pinMode(UNUSED_PIN_1, INPUT_PULLUP);
    pinMode(UNUSED_PIN_2, INPUT_PULLUP);
    pinMode(UNUSED_PIN_3, INPUT_PULLUP);
    pinMode(UNUSED_PIN_5, INPUT_PULLUP);
    pinMode(UNUSED_PIN_6, INPUT_PULLUP);
    pinMode(UNUSED_PIN_14, INPUT_PULLUP);
    pinMode(UNUSED_PIN_15, INPUT_PULLUP);

    // In use pins
    pinMode(TEMPERATURE_UNIT_SELECTOR_INPUT_PIN, INPUT_PULLUP);
    pinMode(DISPLAY_1_SELECT_OUTPUT_PIN, OUTPUT);
    pinMode(DISPLAY_2_SELECT_OUTPUT_PIN, OUTPUT);
    pinMode(DISPLAY_3_SELECT_OUTPUT_PIN, OUTPUT);
    pinMode(THERMISTOR_REFERENCE_SELECT_OUTPUT_PIN, OUTPUT);

    // Analog inputs have to be set to input (no pull-ups)
    pinMode(PSI_ANALOG_INPUT_PIN, INPUT);
    pinMode(ILLUMINATION_ANALOG_INPUT_PIN, INPUT);
    pinMode(REFERENCE_ANALOG_INPUT_PIN, INPUT);
    pinMode(COOLANT_ANALOG_INPUT_PIN, INPUT);
    pinMode(VOLTAGE_ANALOG_INPUT_PIN, INPUT);
}

// Initialize the specified display, set font, size and color
// display: An instance of the Adafruit_SSD1306 class representing the display
//          to be initialized
void initDisplay(Adafruit_SSD1306 &display)
{
    selectDisplay(display);
    display.begin(SSD1306_SWITCHCAPVCC, 0x3C, false);
    display.setTextSize(1);
    display.setTextColor(WHITE);
    display.setFont(&FreeSans18pt7bNum);
    display.clearDisplay();
    display.display();
    forceDisplayRefresh(display);
}

void setup()
{
    configureIOs();
    for (size_t d = 0; d < display_count ; d++)
    {
        initDisplay(*displays[d]);
    }

    // Start with the high reference pull-down value
    setThermistorHighReference(true);

    // Read the onboard jumper.
    // Jupmer absent = Celsius
    // Jupmer present = Fahrenheit
    temperatureUnitIsFahrenheit = ! digitalRead(TEMPERATURE_UNIT_SELECTOR_INPUT_PIN);

    displayIntro();
}

void loop()
{
    float coolant_temp;
    float coolant_psi;
    float supply_voltage;
    bool dayLight;
    int err;

    // The following value are used to compute and enforce the refresh rate
    uint64_t startMs;
    int32_t elapsedMs;
    int32_t waitMs;

    // Sample the current timer counter
    startMs = millis();

    err = getCoolantTempCelsius(coolant_temp);
    if (err == ENOERR) {
        if (coolant_temp != current_coolant_temp)
        updateCoolant(display_1, coolant_temp);
    } else {
        displayFault(display_1);
    }

    err = getCoolantPsi(coolant_psi);
    if (err == ENOERR) {
        if (coolant_psi != current_coolant_psi)
            updatePsi(display_2, coolant_psi);
    } else {
        displayFault(display_2);
    }

    err = getSupplyVoltage(supply_voltage);
    if (err == ENOERR) {
        if (supply_voltage != current_supply_voltage)
            updateSupplyVoltage(display_3, supply_voltage);
    } else {
        displayFault(display_3);
    }

    processDayLight();

    // Wait the correct amount of time to respect the desired refresh rate
    // Note: There is no needs to take the timer overflow into account here. The timer overflows every
    //       50 days, which is much longer than a car would runs continuously
    elapsedMs = (int32_t)(millis() - startMs);
    waitMs = int32_t((int32_t)((1.0 / (float)DISPLAY_REFRESH_RATE_HZ) * 1000.0) - (int32_t)elapsedMs);
    if (waitMs > 0)
        delay(waitMs);
}

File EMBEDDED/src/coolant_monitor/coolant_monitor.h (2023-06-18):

/* 
 * This is the main header file for the RX-8 coolant monitor project.
 * Author: Stephane Gilbert
 * BSD tree clause licence (SPDX: BSD-3-Clause)
*/

// The coolant temperature warning threshold, in Celsius
#define COOLANT_TEMP_WARNING_CELSIUS 110

// The coolant pressure warning threshold, in PSI
#define COOLANT_PSI_WARNING 15

// Display a warning sign when the battery voltage is below or above these values
#define BATTERY_VOLTAGE_LOW_WARNING 11.6
#define BATTERY_VOLTAGE_HIGH_WARNING 14.8

// The speed at which the display refreshes the displayed values
#define DISPLAY_REFRESH_RATE_HZ 4

// Position of the displayed value in the display. Do not change this.
#define TEXT_POS_X 30
#define TEXT_POS_Y 4

// Digital pins definitions
#define UNUSED_PIN_0 0
#define UNUSED_PIN_1 1
#define UNUSED_PIN_2 2
#define UNUSED_PIN_3 3
#define UNUSED_PIN_4 4
#define UNUSED_PIN_5 5
#define UNUSED_PIN_6 6
#define TEMPERATURE_UNIT_SELECTOR_INPUT_PIN 8
#define DISPLAY_1_SELECT_OUTPUT_PIN 10
#define DISPLAY_2_SELECT_OUTPUT_PIN 9
#define DISPLAY_3_SELECT_OUTPUT_PIN 7
#define UNUSED_PIN_14 14
#define UNUSED_PIN_15 15
#define THERMISTOR_REFERENCE_SELECT_OUTPUT_PIN 16

// Analog pin definition
#define PSI_ANALOG_INPUT_PIN A0            // Digital out 18
#define ILLUMINATION_ANALOG_INPUT_PIN A1   // Digital out 19
#define REFERENCE_ANALOG_INPUT_PIN A2      // Digital out 20
#define COOLANT_ANALOG_INPUT_PIN A3        // Digital out 21
#define VOLTAGE_ANALOG_INPUT_PIN A6        // Digital out 4

/* Thermistor value and treshold
 * The Delphi 12160855 or AEM 30-2012 sensor, like all thermistors don't have a linear curve
 * So to have a good precision on the full temperature scale, we use two different resistor value
 * to calculate the temperature. One for the low end to mid, and one for the high end.
 * Since we mesure en engine coolant temperature, the high end reading must be accurate.
 * The reference resistors and the treshold to switch between them are determined by the value below.
 * An hysteresis is used to avoid changing the reference too often.
 */
// For the best results, mesure the actual value on your specific board and use high precision %1 resistor or better.
// Important: Enter the value as float
#define THERMISTOR_RESISTOR_REFERENCE_HIGH 14922.0
// This is the parallel value of both the above reference resistor and a second one
// Important: Enter the value as float
#define THERMISTOR_RESISTOR_REFERENCE_LOW 936.5
// The treshold values to toggle between high resistor and low resistor
#define THERMISTOR_RESISTOR_REFERENCE_LOW_TRESHOLD 55
#define THERMISTOR_RESISTOR_REFERENCE_HIGH_TRESHOLD 50

// There is an onboard tension divider that allow to read the supply voltage (12V).
// The raw voltage is too high for the Arduino, so the voltage is divided with resistors.
// For the best results, mesure the actual values on your specific board and use high precision %1 resistor or better.
// Important: Enter the value as float
// These values below allow a voltage range from 0 to 18V
#define VOLTAGE_DIVIDER_R1 3904.0
#define VOLTAGE_DIVIDER_R2 1477.0

// The following if for analog read.
// For improving accuracy, an external voltage refernece is used and many samples are gathered for
// each analog read operation.
// Reference used for the ADC to accuratly mesure voltage
#define ANALOG_REFERENCE_VOLTAGE 4.096
// Number of sample to read for each analog acquisition
#define ANALOG_SAMPLES_COUNT 5
// The number of time to wait between analog acquisitions.
#define ANALOG_DELAY_BETWEEN_ACQUISITIONS 5

/* ERROR Codes */
#define ENOERR 0
#define ERANGE 1
#define EDIVZERO 2

/* Custom icons definitions.
 * Made with Gimp and converted with image2cpp
 * https://javl.github.io/image2cpp
 * The original file are located in the 'bitmaps' folder
 */
// 'degree_sign sign', 8x10px
const unsigned char epd_bitmap_degree_sign [] PROGMEM= {
    0x3C, 0x66, 0xC3, 0xC3, 0xC3, 0xC3, 0xC3, 0xC3, 0x66, 0x3C, 0xDE, 0x71, 0xB0, 0x78, 0x3C, 0x1E,
    0x0F, 0x07, 0x83, 0xE3, 0x6F, 0x30, 0x18, 0x0C, 0x00, 0x3B, 0x67, 0xC3, 0xC3, 0xC3, 0xC3, 0xC3,
    0xC3, 0x67, 0x3B, 0x03, 0x03, 0x03, 0xDF, 0x31, 0x8C, 0x63, 0x18, 0xC6, 0x00, 0x3E, 0xE3, 0xC0,
    0xC0, 0xE0, 0x3C, 0x07, 0xC3, 0xE3, 0x7E, 0x66, 0xF6, 0x66, 0x66, 0x66, 0x67, 0xC3, 0xC3, 0xC3,
    0xC3, 0xC3, 0xC3, 0xC3, 0xC3, 0xC7, 0x7B, 0xC1, 0xA0, 0x98, 0xCC, 0x42, 0x21, 0xB0, 0xD0, 0x28
};

// 'coolant_icon_c', 24x25px
const unsigned char epd_bitmap_coolant_icon_c [] PROGMEM = {
    0x00, 0x18, 0x00, 0x00, 0x3c, 0x06, 0x00, 0x3c, 0x08, 0x00, 0x3f, 0x88, 0x00, 0x3f, 0x88, 0x00, 
    0x3c, 0x06, 0x00, 0x3c, 0x00, 0x00, 0x3f, 0x80, 0x00, 0x3f, 0x80, 0x00, 0x3c, 0x00, 0x00, 0x3c, 
    0x00, 0x00, 0x3f, 0x80, 0x00, 0x3f, 0x80, 0x00, 0x3c, 0x00, 0x00, 0x3c, 0x00, 0x00, 0x3c, 0x00, 
    0x00, 0x7e, 0x00, 0x00, 0xff, 0x00, 0x00, 0xff, 0x00, 0x00, 0x7e, 0x00, 0x33, 0x3c, 0xcc, 0x0c, 
    0x18, 0x30, 0xc0, 0xc3, 0x03, 0x33, 0x3c, 0xcc, 0x0c, 0x00, 0x30
};

// 'coolant_icon_f', 24x25px
const unsigned char epd_bitmap_coolant_icon_f [] PROGMEM = {
    0x00, 0x18, 0x00, 0x00, 0x3c, 0x0e, 0x00, 0x3c, 0x08, 0x00, 0x3f, 0x8c, 0x00, 0x3f, 0x88, 0x00, 
    0x3c, 0x08, 0x00, 0x3c, 0x00, 0x00, 0x3f, 0x80, 0x00, 0x3f, 0x80, 0x00, 0x3c, 0x00, 0x00, 0x3c, 
    0x00, 0x00, 0x3f, 0x80, 0x00, 0x3f, 0x80, 0x00, 0x3c, 0x00, 0x00, 0x3c, 0x00, 0x00, 0x3c, 0x00, 
    0x00, 0x7e, 0x00, 0x00, 0xff, 0x00, 0x00, 0xff, 0x00, 0x00, 0x7e, 0x00, 0x33, 0x3c, 0xcc, 0x0c, 
    0x18, 0x30, 0xc0, 0xc3, 0x03, 0x33, 0x3c, 0xcc, 0x0c, 0x00, 0x30
};

// 'warning', 31x31px
const unsigned char epd_bitmap_warning_icon [] PROGMEM = {
    0x00, 0x01, 0x00, 0x00, 0x00, 0x03, 0x80, 0x00, 0x00, 0x03, 0x80, 0x00, 0x00, 0x07, 0xc0, 0x00,
    0x00, 0x07, 0xc0, 0x00, 0x00, 0x0f, 0xe0, 0x00, 0x00, 0x0e, 0xe0, 0x00, 0x00, 0x1c, 0x70, 0x00,
    0x00, 0x1c, 0x70, 0x00, 0x00, 0x38, 0x38, 0x00, 0x00, 0x38, 0x38, 0x00, 0x00, 0x70, 0x1c, 0x00,
    0x00, 0x70, 0x1c, 0x00, 0x00, 0xe3, 0x8e, 0x00, 0x00, 0xe3, 0x8e, 0x00, 0x01, 0xc3, 0x87, 0x00,
    0x01, 0xc3, 0x87, 0x00, 0x03, 0x83, 0x83, 0x80, 0x03, 0x83, 0x83, 0x80, 0x07, 0x03, 0x81, 0xc0,
    0x07, 0x03, 0x81, 0xc0, 0x0e, 0x03, 0x80, 0xe0, 0x0e, 0x03, 0x80, 0xe0, 0x1c, 0x00, 0x00, 0x70,
    0x1c, 0x00, 0x00, 0x70, 0x38, 0x03, 0x80, 0x38, 0x38, 0x03, 0x80, 0x38, 0x70, 0x03, 0x80, 0x1c,
    0x70, 0x00, 0x00, 0x1c, 0xff, 0xff, 0xff, 0xfe, 0xff, 0xff, 0xff, 0xfe
};

// 'psi sign', 15x7px
const unsigned char epd_bitmap_psi_sign [] PROGMEM = {
    0xf3, 0xce, 0x92, 0x04, 0x92, 0x04, 0xf3, 0xc4, 0x80, 0x44, 0x80, 0x44, 0x83, 0xce
};
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

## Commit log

2023-04-15 Fix dim on the 3rd display (voltage)
    [coolant_monitor.ino]
2023-04-16 Improved comments, minor bug fixes and refactoring
    [coolant_monitor.h, coolant_monitor.ino]
2023-05-30 Reduced the pressure minimum voltage error threshold
    [coolant_monitor.ino]
2023-06-18 Raised the pressure warning from 13 to 15 psi
